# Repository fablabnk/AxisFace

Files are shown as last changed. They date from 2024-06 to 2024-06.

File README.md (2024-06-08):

https://www.home-wrecker.com/sili-face2.html

Pavlos' version is here: https://github.com/Sysex89/fuzzface

# Components / BOM

2 transistors, 4 resistors, 3 caps and 2 pots

# Description of the circuit

I tried to summarise the key points of the deep-dive into the fuzz-face found [here](https://www.electrosmash.com/fuzz-face).

`The circuit is a simple 2 stage amplifier with a feedback network path. It can be broken down into three parts: Input Stage, Output Stage and Feedback Network. The last block (the Feedback Network) will affect the rest of the analysis because it will influence the most important parameters: voltage gain, input impedance, output impedance and frequency response.`

## Input Stage:

- Input jack
- 2.2uF capacitor:  blocks any DC level, removing hum and protecting the pedal/guitar against dangerous DC levels
- AC128 transistor:
- 33K resistor: sets the main input stage parameters like the voltage gain, bias points, and maximum collector current

## Output Stage:

PNP Common Emitter Amplifier
variable emitter degeneration resistor (RFUZZ=1KΩ)

The output stage of the Fuzz Face circuit boosts the signal to drive the amplifier and enhances harmonic content, resulting in a distinctive, saturated fuzz effect.

Input Capacitor (C2): Blocks DC voltage while allowing AC signal to pass through.
Emitter Resistor (RE): Sets the bias point and stabilizes the transistor.
Emitter Bypass Capacitor (CE): Increases gain and frequency response.
Output Capacitor (C3): Blocks DC voltage while allowing AC signal to pass through, shaping the output frequency response.
Volume Potentiometer (RV1): Adjusts the level of the output signal

## Feedback Network:

- When the fuzz control (1KΩ pot) is set to minimum, a big amount of signal is sent back to the input, creating a big feedback loop and reducing the total pedal gain (left image below).

When the fuzz control increases the attack, the 20uF C2 cap will gradually shunt the negative feedback to the ground, thus letting the circuit operate with more gain (right image below).

# Expected behaviour of the circuit

# Transistor types

Is is important to decide first if we will use NPN or PNP transisors in our design, as this affects the overall topology of the schematic. I decided to use the 2N3906 PNP transistor, as we have a transistor kit similar to [this](https://www.amazon.com/BOJACK-General-Purpose-Transistors-Assortment/dp/B07T61SY9Y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) in our lab. We should be able to easily switch them out later if we don't like the sound.

- BC108 NPN Silicon transistor (Pavlos' version)
- AC128 PNP Geranium transistor (simulatable version, see below)

In an NPN transistor, the layers are arranged as N-type semiconductor sandwiched between two layers of P-type semiconductor.
In a PNP transistor, the layers are arranged as P-type semiconductor sandwiched between two layers of N-type semiconductor.
This difference leads to opposite polarities of voltage and current flow between the emitter, base, and collector terminals for NPN and PNP transistors.

There is also a lot of mythology around geranium transistors - which are favored in guitar pedals for their warm, vintage tone, soft clipping distortion, dynamic response, and historical significance. ideal for us would be to use silicon transistors we have in our lab, 

# Simulation

https://forum.kicad.info/t/fuzz-face-tone-bender-projects-updated-05-22-23/41450

PNP

## Simulating Potentiometers

The 

I would 

Q: Is there a way to plot multiple potentiometer values side by side?

## Another approach: tuning

# Potentiometer values

We don't have 100

# Footswitch

- A range of footswitch wiring methods are described [here](https://stinkfoot.se/archives/2233)
- We will use the "better true bypass" method, as we want to make ususe the DPDT footswitches we already have in stock
- We will try to include the bypass wiring as part of the wiring of our main PCB, but if the layout doesn't make sense, we could design a mini bypass PCB
- In future we prefer to use a 3PDT, so as to also have an LED that shows when the fuzz is on or off

# Power

9V Battery

# Audio Ins/Outs

Q: How do they mount?

# PCB Layout

Q: What case will we use?
A: A recycled metal tin

# JLCPCB Plugin

# Misc

Lots of other circuit resources: https://electronotes.netfirms.com/free.htm

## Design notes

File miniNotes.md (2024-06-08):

Axis Fuzz plan

# TODO

- silkscreen to component values where possible
- label pin headers
- PedalLab logo

# README

As our first PedalLab project, we building an Mayer Axis Fuzz. See thread and schematic [here](https://forum.metropoulos.net/viewtopic.php?t=42896&start=15)

Key points are:
- it uses transistors we already have in stock
- We will chain resistors we have in stock to get some values required by the original circuit
	- 2M2 = 2M + 200K
	- 820K = 680K + 150K
- it will be housed in a hand-cream tin
- it has three controls: two pots and one footswitch
- the PCB will mount to the two pots
- there are two pot issues:
	1. our pots are not of same type (one 9mm, one bourns)
	2. we don't have a 2K 'drive' pot, so will use 1K instead
- the footswitch will be wired point-to-point in 'true bypass' form marked terminals on the PCB
	- see [here)](https://stinkfoot.se/archives/2233)
- same goes for the 1/4" audio jacks (it is unclear where we will mount these currently)
- the pedal will be powered a by 9V battery or DC barrel jack
- we will make use of ground and power planes
- we will spice simulate the circuit within KiCad and keep the simulation symbols in when doing the PCB design also

- do all components fit inside the tin?
- does 0.001uF need to be not ceramic? others too?
- how to do DC barrel jack - point to point

FX Return

in the original circuit their is no footswitch, instead we just have guitar input and distorted output
in our version our guitar input will go first to the footswitch, then depending on the footswitch position
	- route the input signal to the output
	- route the output of the distortion circuit to the output

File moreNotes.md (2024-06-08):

Key aims/design constraints:

- base our design on silicon transistors we already have in stock and avoid 'mystical bullshit'
	- we have 2N2222 2N2907 2N3904 2N3906 A1015 BC327 BC337 C1815 S8050 S8550
- mount the PCB in a repurposed metal case that can be found at our local supermarket
- use DPDT footswitches we already have using a ['true bypass' wiring scheme](https://stinkfoot.se/archives/2233) (for now `no LED, no problem`)
- use pots we already have in stock: 
- used a tried an tested design, so as not to get bogged down in circuit theory
- simulate it as a 'sanity check' before ordering

Single knob, but needs 2N5088: https://www.home-wrecker.com/sili-face2.html

Needs 2K lin and 50K log pot: https://fuzzcentral.ssguitar.com/schematics/axisfuzzschem.gif
- 50K we have

Fuzz Central
Axis Fuzz
diystompboxes.com
Good advice here: http://diy.smallbearelec.com/HowTos/BreadboardSiFF/BreadboardSiFF.htm

2N2222: This is a popular general-purpose NPN transistor and is occasionally used in fuzz face circuits. It can work well in these circuits but might not be as common as some other choices.

2N2907: This is a PNP transistor, less commonly used in fuzz face circuits which typically use NPN transistors. It's more often found in other types of circuits due to its complementary nature to NPN transistors.

2N3904: This is a very commonly used NPN transistor and is frequently used in fuzz face pedal designs. It's known for its affordability and availability, making it a popular choice for DIY projects.

BC337: This is an NPN transistor and is occasionally used in fuzz face circuits, though it might not be as common as some other choices like the 2N3904.

https://www.reddit.com/r/diypedals/comments/13k5sxv/fuzz_face_build_with_2n3904_transistors/

https://fuzzcentral.ssguitar.com/schematics/axisfuzzschem.gif
https://fuzzcentral.ssguitar.com/schematics.php

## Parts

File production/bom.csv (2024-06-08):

Designator | Footprint | Quantity | Value | LCSC Part #
"DRIVE" 2K LIN | PinHeader_1x02_P2.54mm_Vertical | 1 | 2K lin DRIVE
"VOL" 50K LOG | PinHeader_1x03_P2.54mm_Vertical | 1 | 50K log VOL
C1 | CP_Radial_D5.0mm_P2.50mm | 1 | 2.2uF
C2, C3, C7 | CP_Radial_D5.0mm_P2.50mm | 3 | 22uF
C4 | C_Axial_L5.1mm_D3.1mm_P7.50mm_Horizontal | 1 | 1nF
C5, C8 | C_Axial_L5.1mm_D3.1mm_P7.50mm_Horizontal | 2 | 0.1uF
C6 | C_Axial_L5.1mm_D3.1mm_P7.50mm_Horizontal | 1 | 470pF
J10 | PinHeader_1x03_P2.54mm_Vertical_TRS | 1 | AudioIn
J12 | PinHeader_1x02_P2.54mm_Vertical_TS | 1 | AudioOut
J2 | PinHeader_1x01_P2.54mm_Vertical | 1 | FX Return
J3 | PinHeader_1x01_P2.54mm_Vertical | 1 | From FX Send
Q1 | TO-92_Inline_Wide | 1 | 2N3904
Q2 | TO-92_Inline_Wide | 1 | 2N3906
R1 | R_Axial_DIN0207_L6.3mm_D2.5mm_P7.62mm_Horizontal | 1 | 22K
R10, R4 | R_Axial_DIN0207_L6.3mm_D2.5mm_P7.62mm_Horizontal | 2 | 680K
R11, R5 | R_Axial_DIN0207_L6.3mm_D2.5mm_P7.62mm_Horizontal | 2 | 220
R12 | R_Axial_DIN0207_L6.3mm_D2.5mm_P7.62mm_Horizontal | 1 | 47K
R13 | R_Axial_DIN0207_L6.3mm_D2.5mm_P7.62mm_Horizontal | 1 | 200K
R2 | R_Axial_DIN0207_L6.3mm_D2.5mm_P7.62mm_Horizontal | 1 | 180K
R3 | R_Axial_DIN0207_L6.3mm_D2.5mm_P7.62mm_Horizontal | 1 | 10K
R6 | R_Axial_DIN0207_L6.3mm_D2.5mm_P7.62mm_Horizontal | 1 | 100K
R7 | R_Axial_DIN0207_L6.3mm_D2.5mm_P7.62mm_Horizontal | 1 | 150K
R8 | R_Axial_DIN0207_L6.3mm_D2.5mm_P7.62mm_Horizontal | 1 | 39K
R9 | R_Axial_DIN0207_L6.3mm_D2.5mm_P7.62mm_Horizontal | 1 | 2M
V1 | PinHeader_1x02_P2.54mm_Vertical | 1 | 9V

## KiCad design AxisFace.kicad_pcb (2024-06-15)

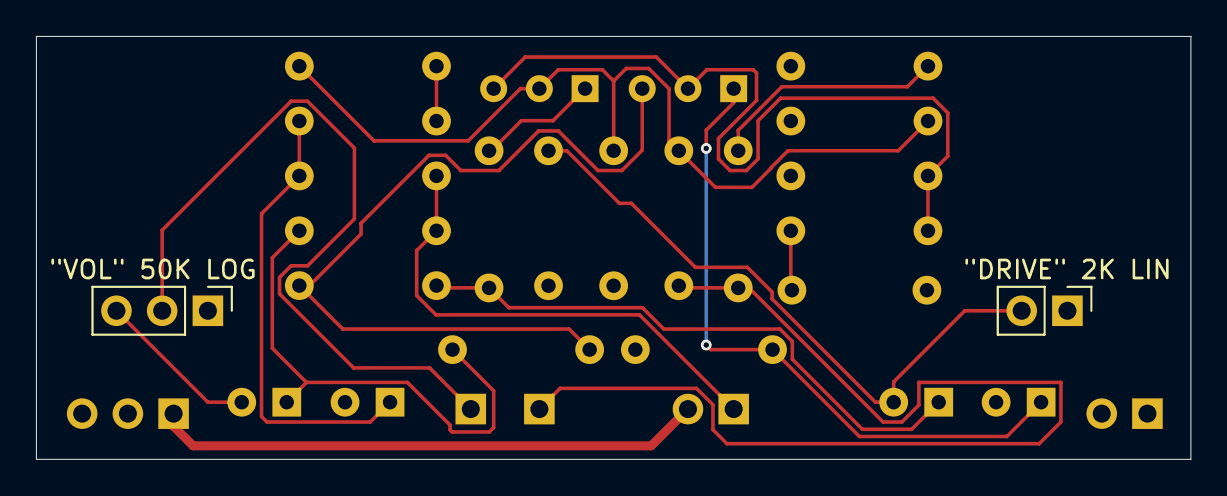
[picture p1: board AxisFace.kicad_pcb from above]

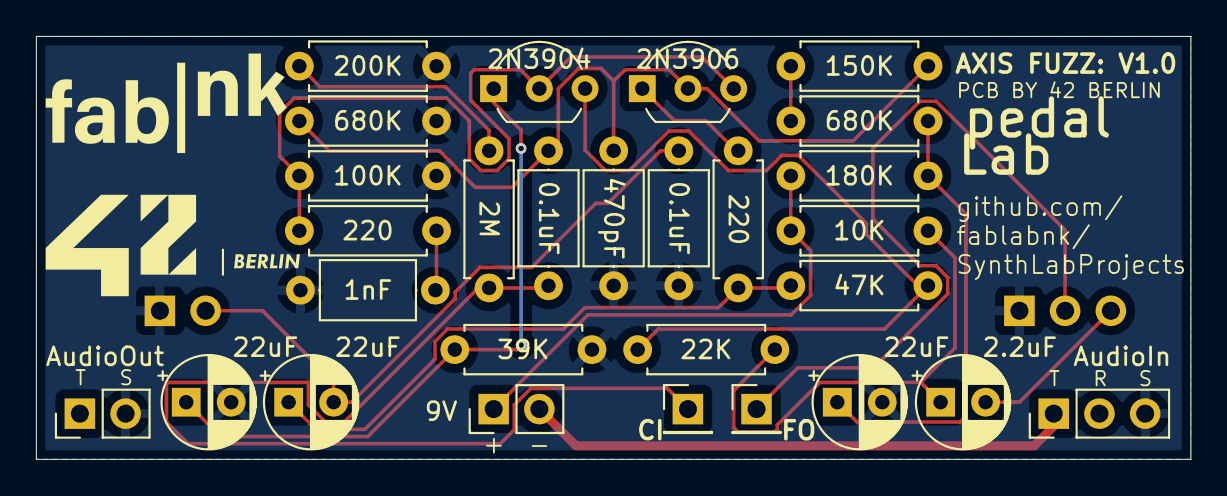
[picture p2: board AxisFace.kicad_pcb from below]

Board: 2 copper layers, 64.1 x 23.5 mm, 30 parts (28 on the bottom side), 18 nets.

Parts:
"DRIVE" 2K LIN: 2K lin DRIVE; PinHeader_1x02_P2.54mm_Vertical
"VOL" 50K LOG: 50K log VOL; PinHeader_1x03_P2.54mm_Vertical
C1: 2.2uF; CP_Radial_D5.0mm_P2.50mm
C2, C3, C7: 22uF; CP_Radial_D5.0mm_P2.50mm
C4: 1nF; C_Axial_L5.1mm_D3.1mm_P7.50mm_Horizontal
C5, C8: 0.1uF; C_Axial_L5.1mm_D3.1mm_P7.50mm_Horizontal
C6: 470pF; C_Axial_L5.1mm_D3.1mm_P7.50mm_Horizontal
J2: FX Return; PinHeader_1x01_P2.54mm_Vertical
J3: From FX Send; PinHeader_1x01_P2.54mm_Vertical
J10: AudioIn; PinHeader_1x03_P2.54mm_Vertical_TRS
J12: AudioOut; PinHeader_1x02_P2.54mm_Vertical_TS
Q1: 2N3904; TO-92_Inline_Wide
Q2: 2N3906; TO-92_Inline_Wide
R1: 22K; R_Axial_DIN0207_L6.3mm_D2.5mm_P7.62mm_Horizontal
R2: 180K; R_Axial_DIN0207_L6.3mm_D2.5mm_P7.62mm_Horizontal
R3: 10K; R_Axial_DIN0207_L6.3mm_D2.5mm_P7.62mm_Horizontal
R4, R10: 680K; R_Axial_DIN0207_L6.3mm_D2.5mm_P7.62mm_Horizontal
R5, R11: 220; R_Axial_DIN0207_L6.3mm_D2.5mm_P7.62mm_Horizontal
R6: 100K; R_Axial_DIN0207_L6.3mm_D2.5mm_P7.62mm_Horizontal
R7: 150K; R_Axial_DIN0207_L6.3mm_D2.5mm_P7.62mm_Horizontal
R8: 39K; R_Axial_DIN0207_L6.3mm_D2.5mm_P7.62mm_Horizontal
R9: 2M; R_Axial_DIN0207_L6.3mm_D2.5mm_P7.62mm_Horizontal
R12: 47K; R_Axial_DIN0207_L6.3mm_D2.5mm_P7.62mm_Horizontal
R13: 200K; R_Axial_DIN0207_L6.3mm_D2.5mm_P7.62mm_Horizontal
V1: 9V; PinHeader_1x02_P2.54mm_Vertical

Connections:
-9V: J10.T, V1.2
GND: "DRIVE" 2K LIN.1, "VOL" 50K LOG.1, C2.2, C3.2, C4.2, C6.2, C8.2, J10.S, J12.S, R6.1, R8.1, R10.1, R13.1
unnamed: C1.1, R1.1, R3.2
unnamed: "VOL" 50K LOG.3, C1.2
unnamed: C2.1, R2.1, R4.2
unnamed: C4.1, R5.2
unnamed: C7.1, R11.1, R12.2
unnamed: "DRIVE" 2K LIN.2, C7.2, C8.1
unnamed: "VOL" 50K LOG.2, J2.1
unnamed: C5.1, J3.1, R9.2
unnamed: Q1.2 (B), Q2.3 (C), R5.1, R6.2
unnamed: Q1.3 (C), R1.2, R12.1
unnamed: C3.1, Q1.1 (E), R8.2
unnamed: C5.2, C6.1, Q2.2 (B), R7.1, R10.2
unnamed: Q2.1 (E), R11.2
unnamed: R2.2, R3.1, V1.1
unnamed: R4.1, R7.2
unnamed: R9.1, R13.2

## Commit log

2024-06-08 ready for production
    [AxisFace.kicad_pcb, AxisFace.kicad_sch, bom.csv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]
2024-06-15 pcb now meets custom design rules for jlcpcb
    [AxisFace.kicad_pcb, bom.csv, designators.csv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]
2024-07-02 moved README and notes into KiCad folder
    [AxisFace.kicad_pcb, AxisFace.kicad_sch, bom.csv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]
